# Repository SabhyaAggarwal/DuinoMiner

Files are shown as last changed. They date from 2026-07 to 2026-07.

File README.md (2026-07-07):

# DuinoMiner
This is a PCB made by me that is used for mining DuinoCoin, a type of cryptocurrency with not too much value. You can mine it with normal small consumer-available chips as well...

## Hardware
### Schematic

Screenshot 2026-07-07 at 3 27 21 PM

### PCB Design

Screenshot 2026-07-07 at 3 27 56 PM

### 3D render

image (12)

## BOM
|Name |Description |Quantity|Total Cost|Link |Distributor |
|---|---|---|---|---|---|
|PCB |Main PCB(cost includes payment fees) |1 |$1.36 |https://aivon.com/ |AIVON |
|Wemos D1 Mini |Main chip for Network connection(cost includes tax) |1 |$2.17 |https://quartzcomponents.com/products/wemos-d1-mini-esp8266-nodemcu-mini-d1-module?variant=39261072392376 |quartz component|
|Pi Pico |The 3 Picos which actually mine(tax inclusive and shipping grouped with wemos) |3 |$12.23 |https://quartzcomponents.com/products/raspberry-pi-pico?variant=37945289801912 |quartz component|
|0.96 inch oled display|OLED display |1 |$1.71 |https://quartzcomponents.com/collections/all/products/oled-display-0-96-inch-i2c-interface-4-pin-blue-ssd1306|quartz component|
|40 pin male header |Header pins for the pi picos as they are not included(tax inclusive and shipping grouped with wemos)|3 |$0.26 |https://quartzcomponents.com/products/40-pin-break-away-headers-straight-male-headers?variant=31898065633415 |quartz component|

## Notes

For setup there is a great onboarding setup shown on the OLED screen and you can manage it using the web UI and all. The firmware is taken from https://github.com/JK-Rolling/DuinoI2C_ESP

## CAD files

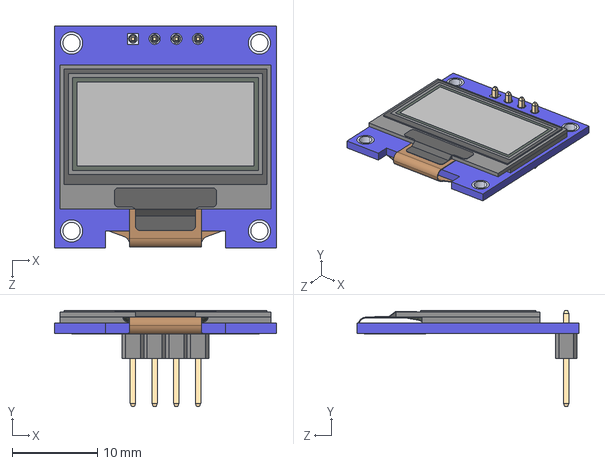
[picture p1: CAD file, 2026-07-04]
PCB/DM-OLED096-636.step
26.0 x 11.3 x 26.0 mm
DM-OLED096-636_Module
DM-OLED096-636_Panel

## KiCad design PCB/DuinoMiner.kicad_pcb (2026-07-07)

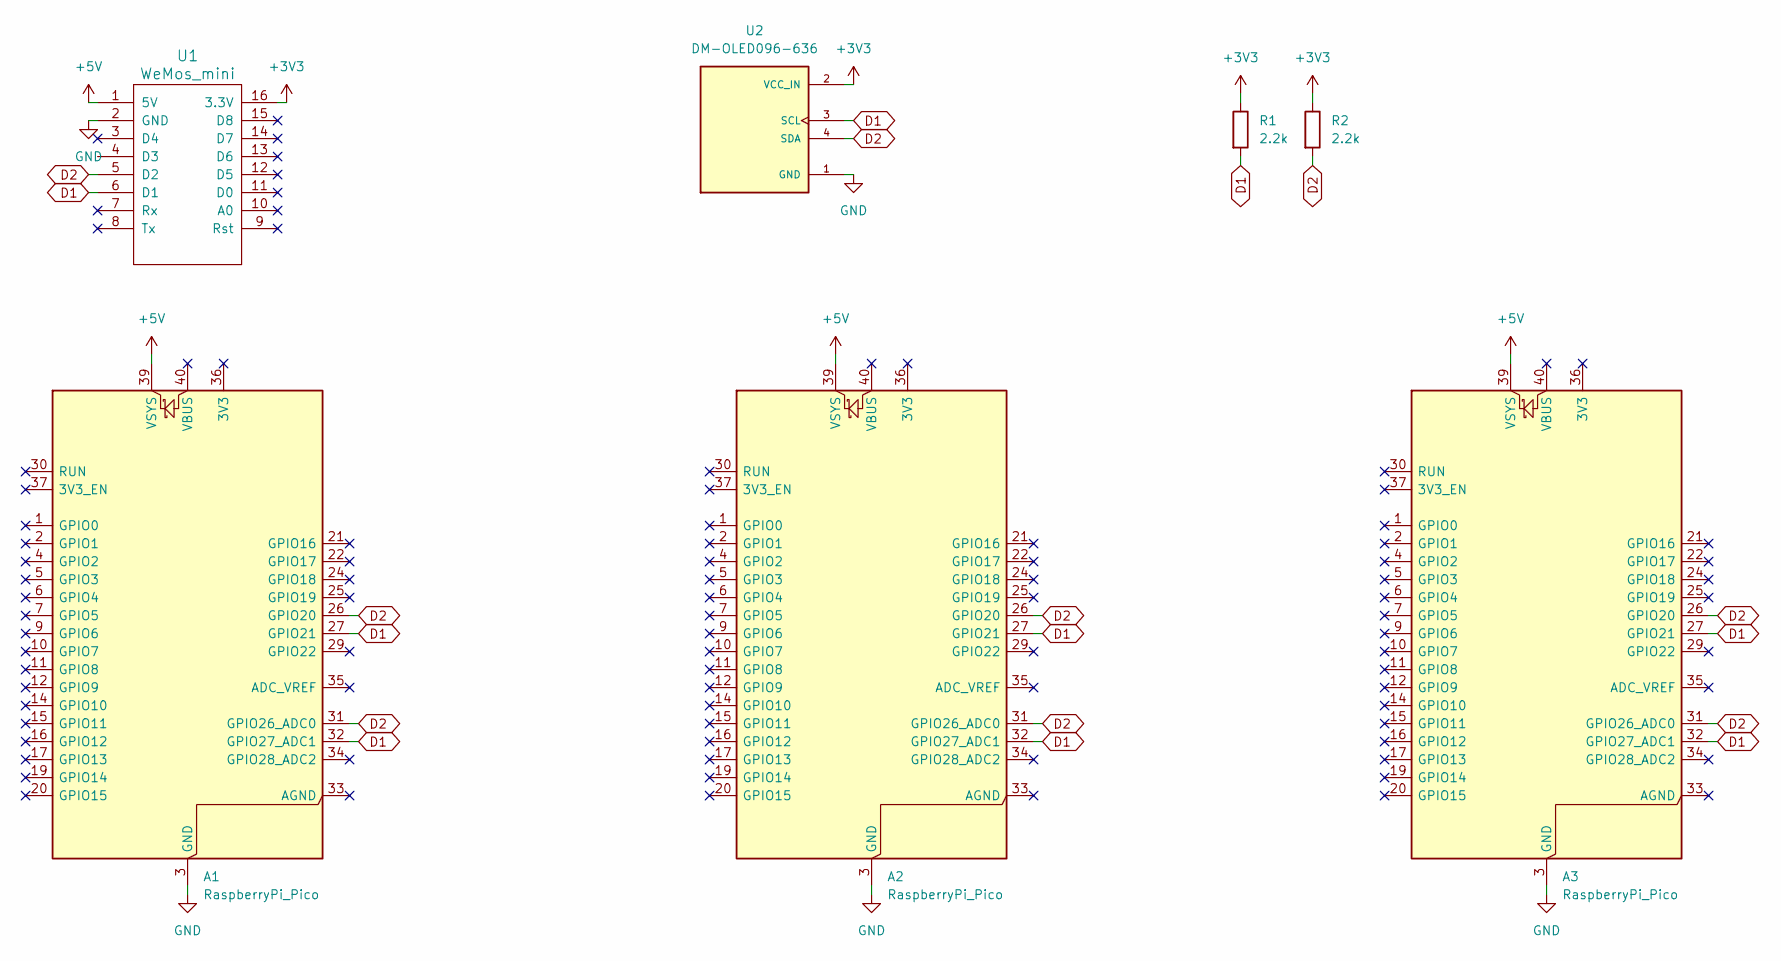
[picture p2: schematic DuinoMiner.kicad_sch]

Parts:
A1, A2, A3: RaspberryPi_Pico; RaspberryPi_Pico_Common_THT
R1, R2: 2.2k; R_Axial_DIN0204_L3.6mm_D1.6mm_P7.62mm_Horizontal
U1: WeMos_mini; D1_mini_board
U2: DM-OLED096-636; MODULE_DM-OLED096-636; PARTREV 2018-09-10

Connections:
+3V3: R1.1, R2.1, U1.16 (3.3V), U2.2 (VCC_IN)
+5V: A1.39 (VSYS), A2.39 (VSYS), A3.39 (VSYS), U1.1 (5V)
D1: A1.27 (GPIO21), A1.32 (GPIO27_ADC1), A2.27 (GPIO21), A2.32 (GPIO27_ADC1), A3.27 (GPIO21), A3.32 (GPIO27_ADC1), R1.2, U1.6 (D1), U2.3 (SCL)
D2: A1.26 (GPIO20), A1.31 (GPIO26_ADC0), A2.26 (GPIO20), A2.31 (GPIO26_ADC0), A3.26 (GPIO20), A3.31 (GPIO26_ADC0), R2.2, U1.5 (D2), U2.4 (SDA)
GND: A1.3 (GND), A1.8 (GND), A1.13 (GND), A1.18 (GND), A1.23 (GND), A1.28 (GND), A1.38 (GND), A2.3 (GND), A2.8 (GND), A2.13 (GND), A2.18 (GND), A2.23 (GND), A2.28 (GND), A2.38 (GND), A3.3 (GND), A3.8 (GND), A3.13 (GND), A3.18 (GND), A3.23 (GND), A3.28 (GND), A3.38 (GND), U1.2 (GND), U2.1 (GND)

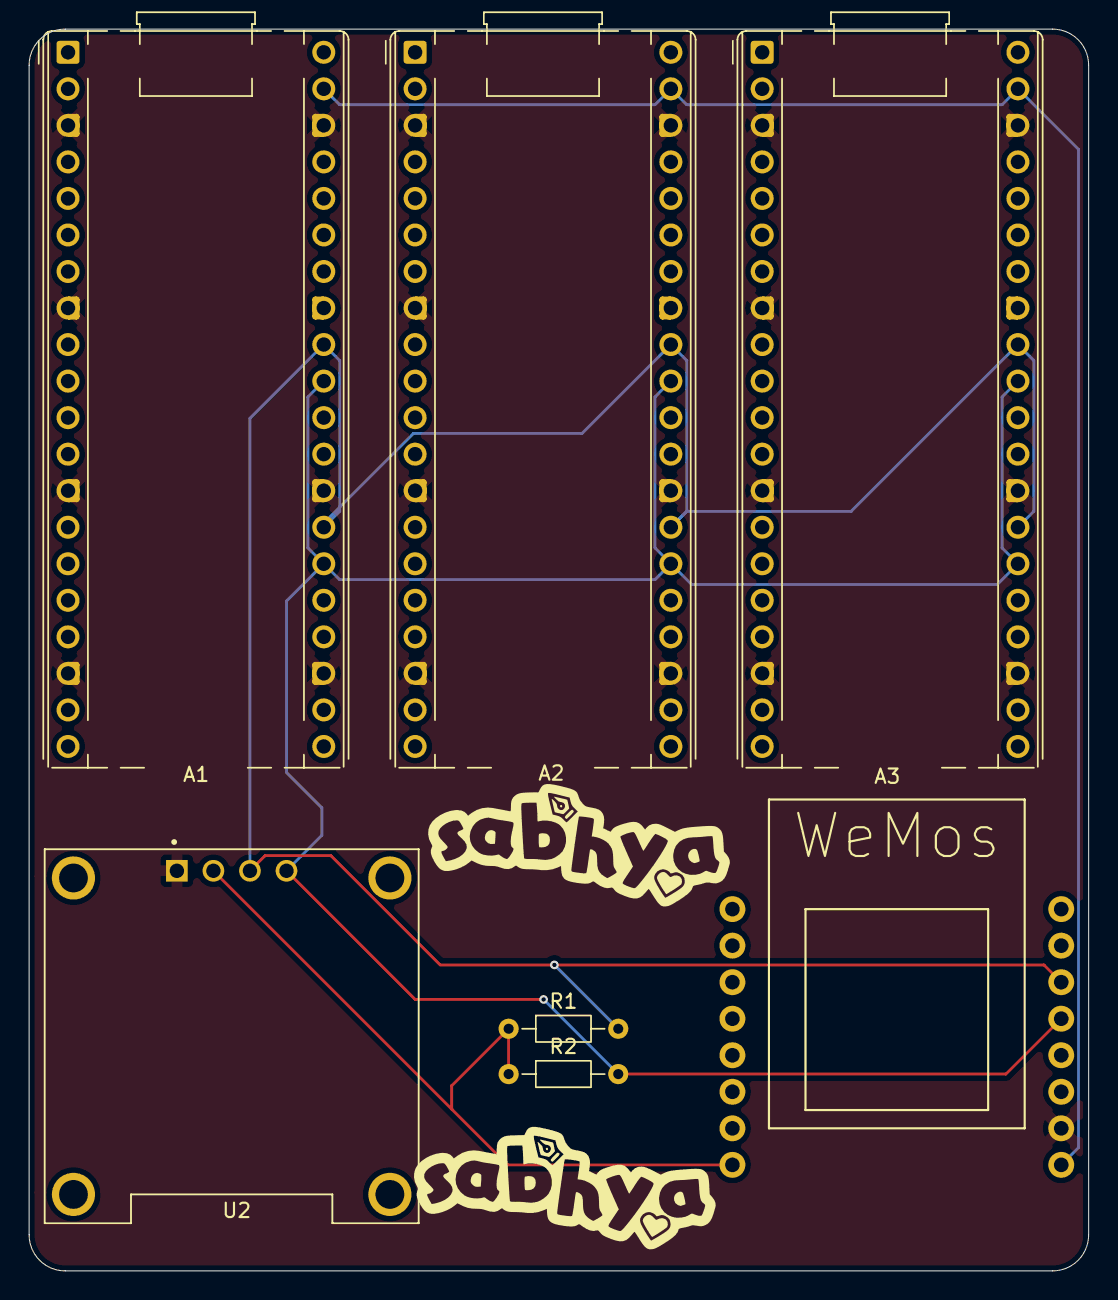
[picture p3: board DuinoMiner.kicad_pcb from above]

Board: 2 copper layers, 73.7 x 86.3 mm, 7 parts (1 on the bottom side), 5 nets.

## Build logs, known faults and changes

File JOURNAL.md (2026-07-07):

---
title: "DuinoMiner: Raspberry Pi-Based DuinoCoin Cryptocurrency Mining Rig"
author: "SabhyaAggarwal"
description: "It's a small PCB which mines DuinoCoin"
created_at: "2026-07-07"
---

# July 7: Made the PCB

I forgot to make the journals. It was only one session. I designed the PCB real quick and made it really well. It looks really good and it was not too costly...

DuinoMiner PCB

**Total time spent: 6 hours**

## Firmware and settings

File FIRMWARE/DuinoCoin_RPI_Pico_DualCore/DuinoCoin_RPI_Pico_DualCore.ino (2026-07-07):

/*
 * DuinoCoin_RPI_Pico_DualCore.ino
 * created by JK Rolling
 * 27 06 2022
 * 
 * Dual core and dual I2C (400kHz/1MHz)
 * DuinoCoin worker
 * 
 * See kdb.ino on Arduino IDE settings to compile for RP2040
 * 
 * with inspiration from 
 * * Revox (Duino-Coin founder)
 * * Ricaun (I2C Nano sketch)
 * 
Sketch uses 74300 bytes (3%) of program storage space. Maximum is 2093056 bytes.
Global variables use 12660 bytes (4%) of dynamic memory, leaving 249484 bytes for local variables. Maximum is 262144 bytes.
 */

#pragma GCC optimize ("-Ofast")

#include <Wire.h>
#include "pico/mutex.h"
extern "C" {
  #include <hardware/watchdog.h>
};

/****************** USER MODIFICATION START ****************/
#define DEV_INDEX                   0
#define I2CS_START_ADDRESS          8
#define WIRE_CLOCK                  400000              // >>> see kdb before changing this I2C clock frequency <<<
#define I2C0_SDA                    12
#define I2C0_SCL                    13
#define I2C1_SDA                    14
#define I2C1_SCL                    15
#define CRC8_EN                     true
#define WDT_EN                      true
#define CORE_BATON_EN               false
#define LED_EN                      true
#define SENSOR_EN                   true
#define SINGLE_CORE_ONLY            false               // >>> see kdb before setting it to true <<<
#define WORKER_NAME                 "rp2040"
#define NEOPIXEL_EN                 false               // >>> see kdb before setting it to true <<<
/****************** USER MODIFICATION END ******************/
/*---------------------------------------------------------*/
/****************** FINE TUNING START **********************/
#if NEOPIXEL_EN
  #define LED_PIN                     16  // RP2040_ZERO:16, Maker Pi Pico:28
#else
  #define LED_PIN                     LED_BUILTIN
#endif
#define LED_BRIGHTNESS              255                 // 1-255
#define BLINK_SHARE_FOUND           1
#define BLINK_SETUP_COMPLETE        2
#define BLINK_BAD_CRC               3
#define WDT_PERIOD                  8300
// USB-Serial --> Serial
// UART0-Serial --> Serial1 (preferred, connect FTDI RX pin to Pico GP0)
#define SERIAL_LOGGER               Serial1
#define BAUDRATE                    115200
#define I2C0                        Wire
#define I2C1                        Wire1
#define DIFF_MAX                    1000
#define MCORE_WDT_THRESHOLD         20
/****************** FINE TUNING END ************************/

#ifdef SERIAL_LOGGER
#define SerialBegin()               SERIAL_LOGGER.begin(BAUDRATE);
#define SerialPrint(x)              SERIAL_LOGGER.print(x);
#define SerialPrintln(x)            SERIAL_LOGGER.println(x);
#else
#define SerialBegin()
#define SerialPrint(x)
#define SerialPrintln(x)
#endif

#if SINGLE_CORE_ONLY
#define DISABLE_2ND_CORE
#endif

// prototype
void Blink(uint8_t count, uint8_t pin);
void BlinkFade(uint8_t led_brightness);
bool repeating_timer_callback(struct repeating_timer *t);

static String DUCOID;
static mutex_t serial_mutex;
static mutex_t led_fade_mutex;
static bool core_baton;
static bool wdt_pet = true;
static uint16_t wdt_period_half = WDT_PERIOD/2;
// 40+40+20+3 is the maximum size of a job
const uint16_t job_maxsize = 104;
byte i2c1_addr=0;
bool core0_started = false, core1_started = false;
uint32_t core0_shares = 0, core0_shares_ss = 0, core0_shares_local = 0;
uint32_t core1_shares = 0, core1_shares_ss = 0, core1_shares_local = 0;
struct repeating_timer timer;
uint8_t led_brightness = 255;

// protect scarce resource
void printMsg(String msg) {
  uint32_t owner;
  if (!mutex_try_enter(&serial_mutex, &owner)) {
    if (owner == get_core_num()) return;
    mutex_enter_blocking(&serial_mutex);
  }
  SerialPrint(msg);
  mutex_exit(&serial_mutex);
}

void printMsgln(String msg) {
  printMsg(msg+"\n");
}

#include "core.h"
// initialize static members
core* core::instance0 = nullptr;
core* core::instance1 = nullptr;

// instantiate slaves
core bus0(&I2C0, 2 * DEV_INDEX + I2CS_START_ADDRESS,     I2C0_SDA, I2C0_SCL);
core bus1(&I2C1, 2 * DEV_INDEX + I2CS_START_ADDRESS + 1, I2C1_SDA, I2C1_SCL);

// Core0
void setup() {
  bool print_on_por = true;
  SerialBegin();

  // initialize mutex
  mutex_init(&serial_mutex);
  mutex_init(&led_fade_mutex);
  
  // core status indicator
  if (LED_EN) {
    pinMode(LED_PIN, OUTPUT);
    add_repeating_timer_ms(10, repeating_timer_callback, NULL, &timer);
  }

  // initialize pico internal temperature sensor
  if (SENSOR_EN) {
    enable_internal_temperature_sensor();
  }

  // initialize watchdog
  if (WDT_EN) {
    if (watchdog_caused_reboot()) {
      printMsgln(F("\nRebooted by Watchdog!"));
      Blink(BLINK_SETUP_COMPLETE, LED_PIN);
      print_on_por = false;
    }
    // Enable the watchdog, requiring the watchdog to be updated every 8000ms or the chip will reboot
    // Maximum of 0x7fffff, which is approximately 8.3 seconds
    // second arg is pause on debug which means the watchdog will pause when stepping through code
    watchdog_enable(WDT_PERIOD, 1);
  }
  
  // let core0 run first
  core_baton = true;
  
  DUCOID = get_DUCOID();
  bus0.bus_setup();
  Blink(BLINK_SETUP_COMPLETE, LED_PIN);
  if (print_on_por) {
    printMsgln("DUCOID: " + DUCOID);
    printMsgln("I2CS_START_ADDRESS: "+String(I2CS_START_ADDRESS));
    printMsgln("DEV_INDEX: "+String(DEV_INDEX));
    printMsgln("WIRE_CLOCK: "+String(WIRE_CLOCK));
    printMsgln("I2C0_SDA: "+String(I2C0_SDA));
    printMsgln("I2C0_SCL: "+String(I2C0_SCL));
    printMsgln("I2C1_SDA: "+String(I2C1_SDA));
    printMsgln("I2C1_SCL: "+String(I2C1_SCL));
    printMsgln("CRC8_EN: "+String(CRC8_EN));
    printMsgln("WDT_EN: "+String(WDT_EN));
    printMsgln("CORE_BATON_EN: "+String(CORE_BATON_EN));
    printMsgln("LED_EN: "+String(LED_EN));
    printMsgln("SENSOR_EN: "+String(SENSOR_EN));
    printMsgln("SINGLE_CORE_ONLY: "+String(SINGLE_CORE_ONLY));
  }
  printMsgln("core" + String(get_core_num()) + ": startup done!");
}

void loop() {
  if (core_baton || !CORE_BATON_EN) {
    if (bus0.coreLoop()) {
      core0_started = true;
      printMsg("core" + String(get_core_num()) + ": ");
      printMsgln(bus0.getResponse());
      BlinkFade(led_brightness);
      if (WDT_EN && wdt_pet) {
        watchdog_update();
      }
      
      if (core0_started && core1_started && !SINGLE_CORE_ONLY) {
        core0_shares++;
        if (core1_shares != core1_shares_ss) {
          core1_shares_ss = core1_shares;
          core1_shares_local = 0;
        }
        else {
          if ((MCORE_WDT_THRESHOLD - core1_shares_local) < MCORE_WDT_THRESHOLD)
            printMsgln("core" + String(get_core_num()) + ": core1 " + String(MCORE_WDT_THRESHOLD - core1_shares_local) + " remaining count to WDT pet disable");
          if (core1_shares_local >= MCORE_WDT_THRESHOLD) {
            printMsgln("core" + String(get_core_num()) + ": Detected core1 hung. Disable WDT pet");
            wdt_pet = false;
          }
          if ((MCORE_WDT_THRESHOLD - core1_shares_local) != 0) {
            core1_shares_local++;
          }
        }
      }
    }
    if (!SINGLE_CORE_ONLY)
      core_baton = false;
  }
}

#ifndef DISABLE_2ND_CORE
// Core1
void setup1() {
  sleep_ms(100);
  bus1.bus_setup();
  Blink(BLINK_SETUP_COMPLETE, LED_PIN);
  printMsgln("core" + String(get_core_num()) + ": startup done!");
}

void loop1() {
  if (!core_baton || !CORE_BATON_EN) {
    if (bus1.coreLoop()) {
      core1_started = true;
      printMsg("core" + String(get_core_num()) + ": ");
      printMsgln(bus1.getResponse());
      BlinkFade(led_brightness);
      if (WDT_EN && wdt_pet) {
        watchdog_update();
      }

      if (core0_started && core1_started && !SINGLE_CORE_ONLY) {
        core1_shares++;
        if (core0_shares != core0_shares_ss) {
          core0_shares_ss = core0_shares;
          core0_shares_local = 0;
        }
        else {
          if ((MCORE_WDT_THRESHOLD - core0_shares_local) < MCORE_WDT_THRESHOLD)
            printMsgln("core1: core0 " + String(MCORE_WDT_THRESHOLD - core0_shares_local) + " remaining count to WDT pet disable");
          if (core0_shares_local >= MCORE_WDT_THRESHOLD) {
            printMsgln("core" + String(get_core_num()) + ": Detected core0 hung. Disable WDT pet");
            wdt_pet = false;
          }
          if ((MCORE_WDT_THRESHOLD - core0_shares_local) != 0) {
            core0_shares_local++;
          }
        }
      }
    }
    core_baton = true;
  }
}
#endif

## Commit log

2026-07-04 Add PCB files
    [DM-OLED096-636.step, DuinoMiner.kicad_pcb, DuinoMiner.kicad_sch]
2026-07-04 Organization + Add Gerbers
    [DM-OLED096-636.step, DuinoMiner.kicad_pcb, DuinoMiner.kicad_sch]
2026-07-07 Fix BOM
    [BOM.csv]
2026-07-07 Fix BOM again
    [BOM.csv, DuinoMiner.kicad_pcb]
